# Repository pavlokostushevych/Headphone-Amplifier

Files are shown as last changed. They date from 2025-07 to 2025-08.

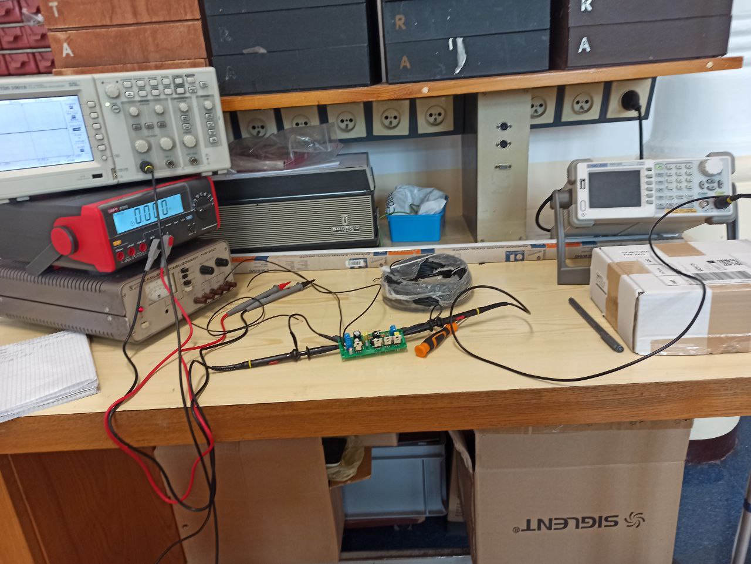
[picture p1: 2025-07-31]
photos/Testing Device.jpg

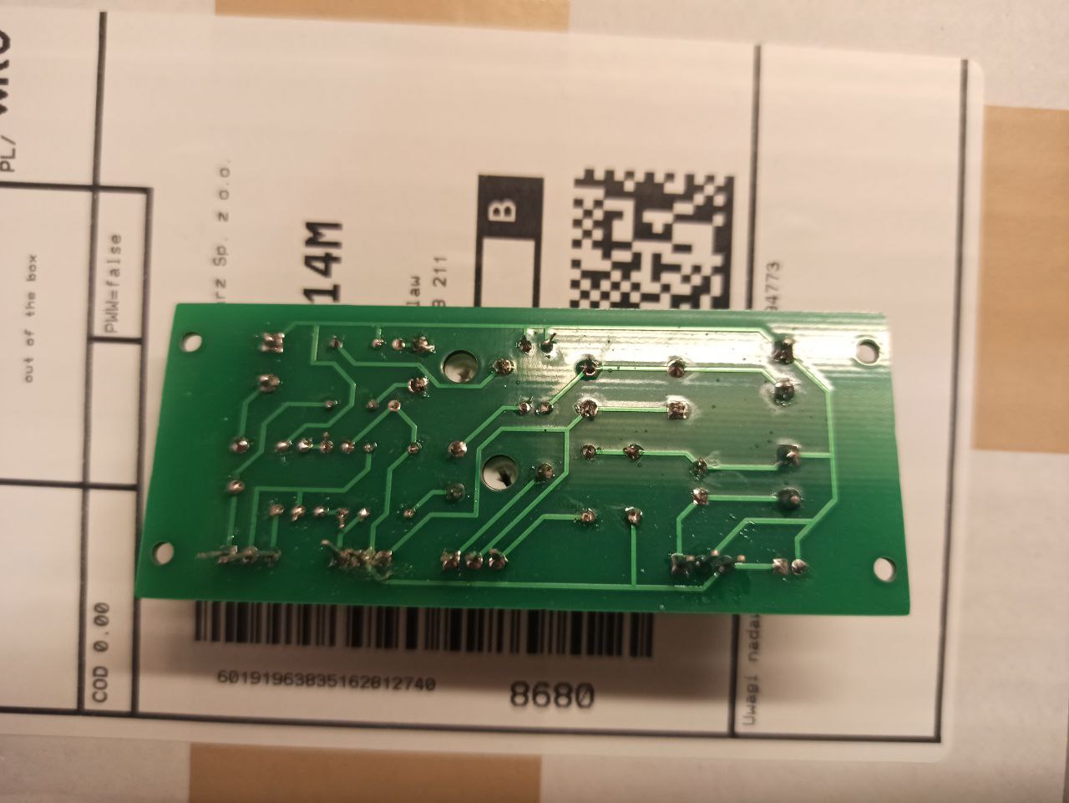
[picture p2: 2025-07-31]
photos/Actual Photo of the PCB from the Soldering Side.jpg

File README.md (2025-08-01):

📄 Wersja polska poniżej – [Przejdź do wersji PL](#pl)

# 🎧 Headphone Amplifier

Class A headphone amplifier project — designed, simulated, and tested.

---

## 📂 Project Structure

- [`docs/`](./docs) — presentations of analysis and simulation in LTspice  
  - Polish version: *[Symulacja i analiza wzmacniacza słuchawkowego klasy A w LTspice](./docs/Symulacja%20i%20analiza%20wzmacniacza%20słuchawkowego%20klasy%20A%20w%20LTspice.pdf)*  
  - English version: *[LTspice Simulation and Analysis of Class A Headphone Amplifier](./docs/LTspice%20Simulation%20and%20Analysis%20of%20Class%20A%20Headphone%20Amplifier.pdf)*  

- [`pcb/`](./pcb) — Gerber files and a screenshot from Gerber Viewer for quick [PCB](./pcb/pcb_gerber_preview.png)
 preview  

- [`photos/`](./photos) — images and visualizations of the device  
  - [3D Simulated View of the PCB](./photos/3D%20Simulated%20View%20of%20the%20PCB.jpg)
  - [Actual Photo of the PCB from the Soldering Side](./photos/Actual%20Photo%20of%20the%20PCB%20from%20the%20Soldering%20Side.jpg)
  - [Testing Device](./photos/Testing%20Device.jpg)

---

## 🛠️ Project Description

The headphone amplifier was designed based on analysis and simulation done in LTspice. The full project includes:  
- Component selection and simulation  
- Schematic and PCB design in KiCad  
- PCB manufacturing files (Gerber)  
- Assembly and soldering of components  
- Testing using power supply, oscilloscope, and multimeter  

---

## 📁 How to Use

- To review the analysis and simulations, please check the PDF files in the [`docs/`](./docs) folder.  
- The Gerber files located in the [`pcb/`](./pcb) folder can be viewed using a Gerber viewer software such as KiCad Gerber Viewer.  
- The [`photos/`](./photos) folder contains visualizations and real photos of the device.  

---

## 📬 Contact

If you have any questions, feel free to reach out:  
- Email: pavlo.kostushevych@gmail.com  
- LinkedIn: [linkedin.com/in/pavlo-kostushevych-ab364b376](https://www.linkedin.com/in/pavlo-kostushevych-ab364b376/)

---

*Thank you for your interest in my project!*

---
## PL

# 🎧 Projekt wzmacniacza słuchawkowego

Projekt wzmacniacza słuchawkowego klasy A — zaprojektowany, zwymiarowany i przetestowany.

---

## 📂 Struktura projektu

- [`docs/`](./docs) — prezentacje analizy i symulacji układu w LTspice  
  - Polskojęzyczna: *[Symulacja i analiza wzmacniacza słuchawkowego klasy A w LTspice](./docs/Symulacja%20i%20analiza%20wzmacniacza%20słuchawkowego%20klasy%20A%20w%20LTspice.pdf)*   
  - Angielska: *[LTspice Simulation and Analysis of Class A Headphone Amplifier](./docs/LTspice%20Simulation%20and%20Analysis%20of%20Class%20A%20Headphone%20Amplifier.pdf)*   

- [`pcb/`](./pcb) — pliki Gerber oraz zrzut ekranu z Gerber Viewer do szybkiego podglądu projektu [PCB](./pcb/pcb_gerber_preview.png)  

- [`photos/`](./photos) — zdjęcia i wizualizacje urządzenia  
  - [3D Simulated View of the PCB](./photos/3D%20Simulated%20View%20of%20the%20PCB.jpg)
  - [Actual Photo of the PCB from the Soldering Side](./photos/Actual%20Photo%20of%20the%20PCB%20from%20the%20Soldering%20Side.jpg)
  - [Testing Device](./photos/Testing%20Device.jpg)

---

## 🛠️ Opis projektu

Wzmacniacz słuchawkowy został zaprojektowany na podstawie analizy i symulacji w LTspice. Całość projektu obejmuje:  
- Dobór i symulację komponentów  
- Projektowanie schematu i PCB w KiCad  
- Wykonanie płytek PCB (plik Gerber)  
- Montaż i lutowanie elementów  
- Testowanie działania za pomocą zasilacza, oscyloskopu i multimetru  

---

## 📁 Jak używać

- Aby przejrzeć analizę i symulacje, zapoznaj się z plikami PDF w folderze [`docs/`](./docs).  
- Pliki Gerber dostępne w folderze [`pcb/`](./pcb) można otworzyć w programie do podglądu Gerber, np. KiCad Gerber Viewer.  
- W folderze [`photos/`](./photos) znajdziesz wizualizacje i zdjęcia rzeczywistego urządzenia.  

---

## 📬 Kontakt

W razie pytań zapraszam do kontaktu:  
- Email: pavlo.kostushevych@gmail.com  
- LinkedIn: [linkedin.com/in/pavlo-kostushevych-ab364b376](https://www.linkedin.com/in/pavlo-kostushevych-ab364b376/)

---

*Dziękuję za zainteresowanie moim projektem!*

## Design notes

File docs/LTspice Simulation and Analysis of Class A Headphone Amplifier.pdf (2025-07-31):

## ELECTRONIC CIRCUIT DESIGN PROJECT

PROJECT TOPIC: CLASS A HEADPHONE AMPLIFIER PAVLO KOSTUSHEVYCH

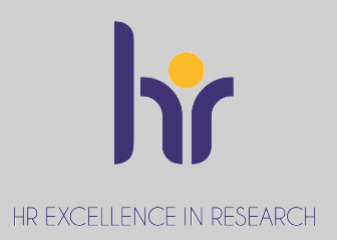
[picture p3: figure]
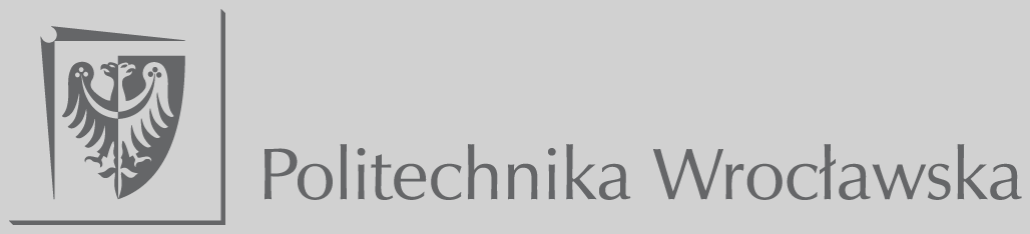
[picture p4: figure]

# Project Schematic

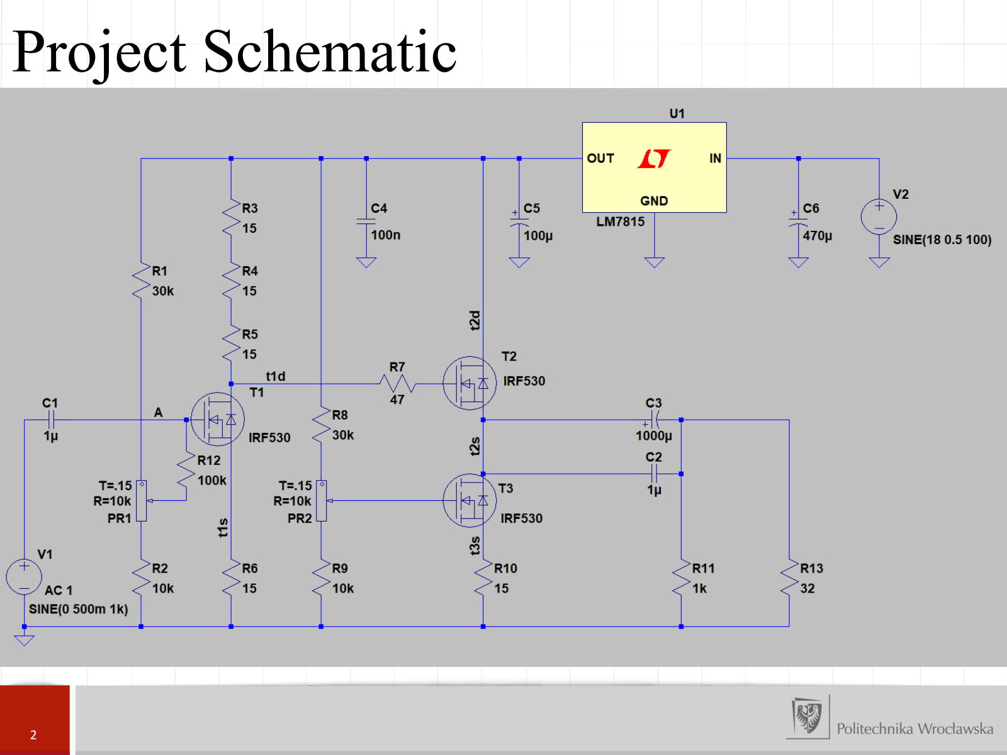
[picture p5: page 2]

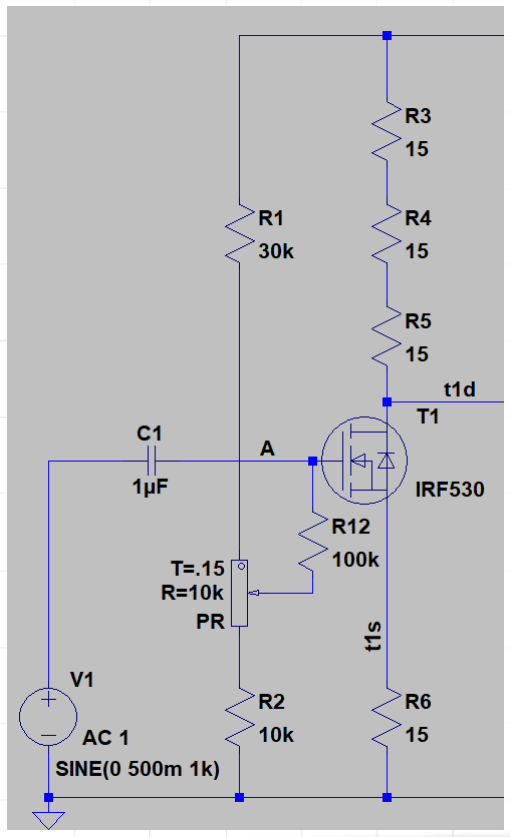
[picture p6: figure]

- The signal is passed through capacitor C1 to the gate of the MOSFET transistor T1.This transistor amplifies the signal by a factor of three, which means the gain is proportional to the ratio of resistors R3, R4, and R5 to resistor R6.This level of amplification is sufficient to connect the amplifier directly to the line output of devices such as CD players, MiniDisc players, or cassette decks.Three identical resistors R3–R5 were used instead of a single 47Ω resistor solely to reduce power dissipation, which totals 450 mW.

# How Does It Work?

## Green input signal: 0.5 V Blue output signal: (12 − 9) / 2 = 1.5 V

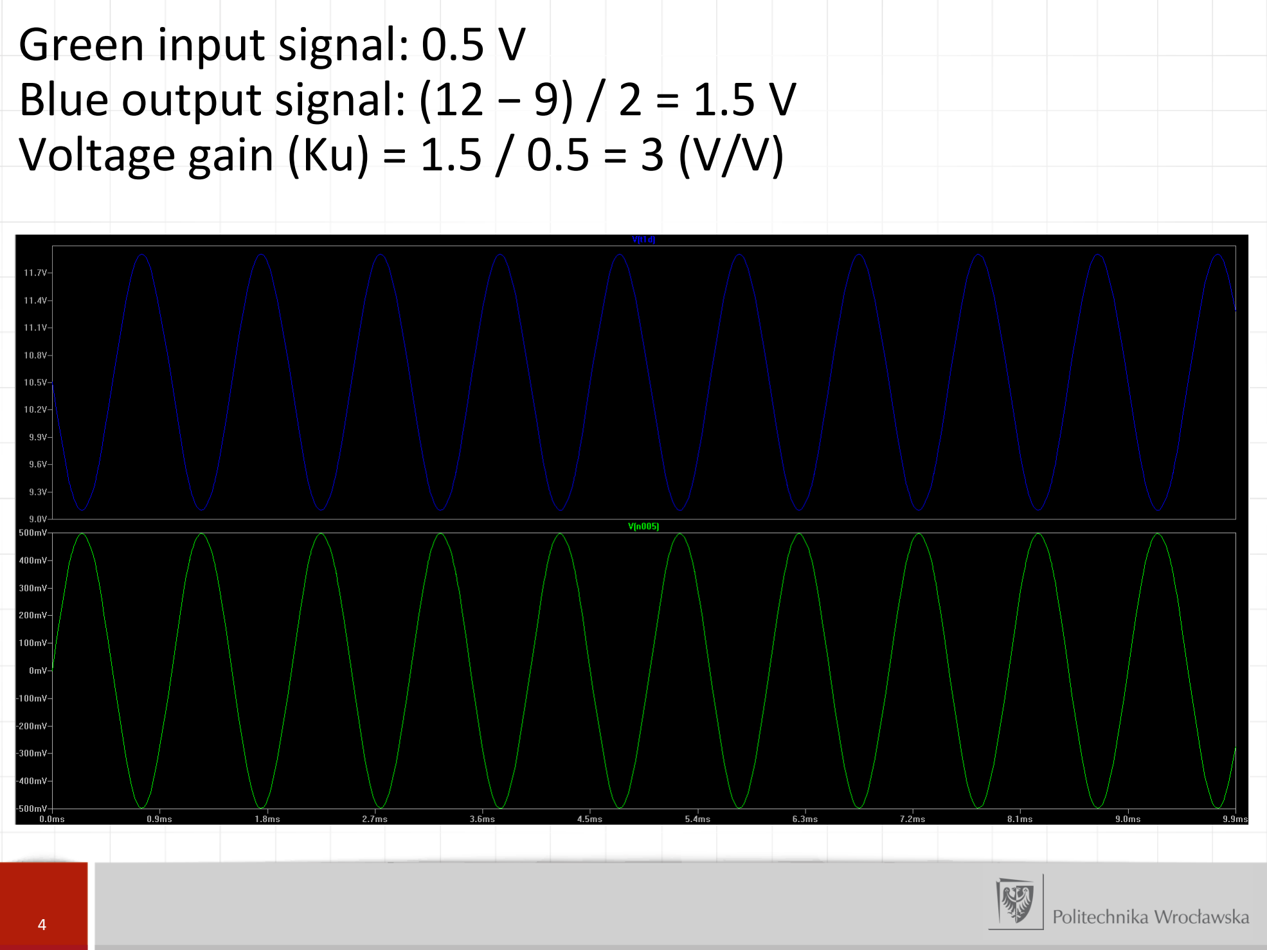
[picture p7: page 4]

## Voltage gain (Ku) = 1.5 / 0.5 = 3 (V/V)

## - The signal, amplified threefold

from the drain of transistor T1,

## is fed to the gate of transistor T2, which operates as a buffer (source follower). To prevent potential oscillations at high frequencies, a low-value resistor R7 is added. To reduce distortion, the buffer T2 is not

loaded with a resistor; instead,

## a current source implemented

using transistor T3 is used.

# How Does It Work?

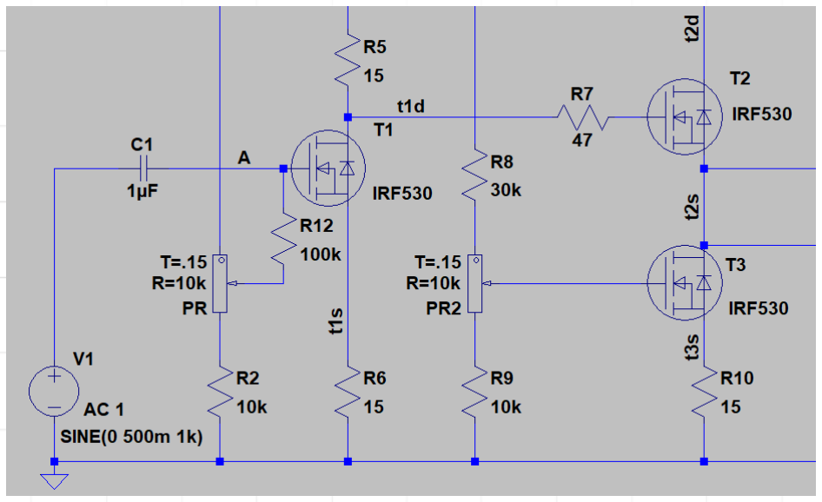
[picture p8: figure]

- To prevent interference from the power supply circuits, a well-regulated supply voltage is required. A supply voltage of 15 V is sufficient to achieve an output power greater than 100 mW into typical
headphones with an impedance
of 32 Ω. However, due to the voltage drop across the regulator, the voltage on capacitor C6 should never be lower than 18 V to ensure stable and interference-free operation of the amplifier.

# How Does It Work?

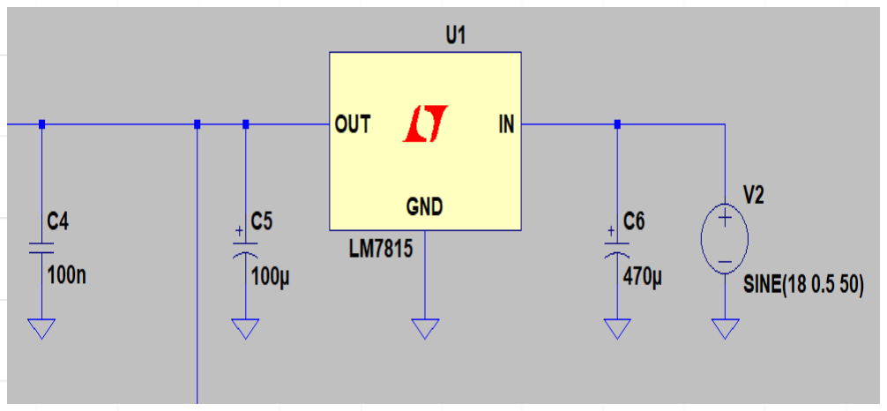
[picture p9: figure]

## Power supply parameters (green signal): 18 V with 0.5 V ripple at 100

Hz

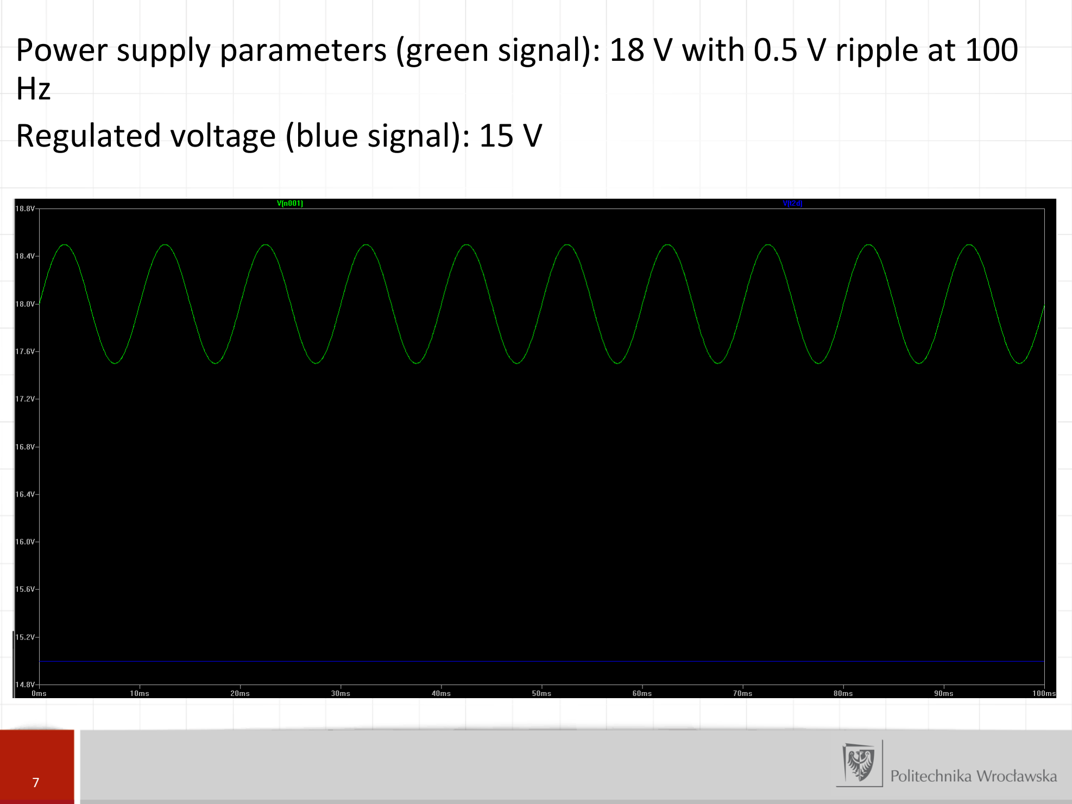
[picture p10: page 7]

## Regulated voltage (blue signal): 15 V

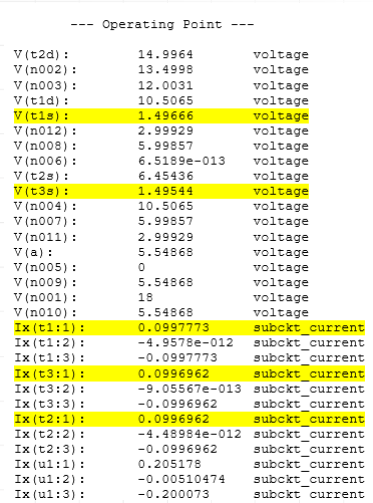
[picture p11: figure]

- To achieve an output power of 100 mW, the quiescent current of the output stage — that is, the quiescent current of transistors T1, T2, and T3 — should be 100 mA or higher. The quiescent currents of T1 and T2+T3 are determined by the values of resistors R6, R10, as well as the voltages at the gates of T1 and T3.The trimmer potentiometers PR1 and PR2 are adjusted so that the quiescent current causes a voltage drop of 1.5 V across resistors R6 (T1s) and R10 (T3s). If these resistors have a value of 15 Ω, this occurs at a quiescent current of 100 mA. Therefore, the entire amplifier — or rather one channel of a stereo amplifier — will draw approximately 200 mA.

# How Does It Work?

## Amplitude characteristic of output voltage (blue) to input voltage (green)

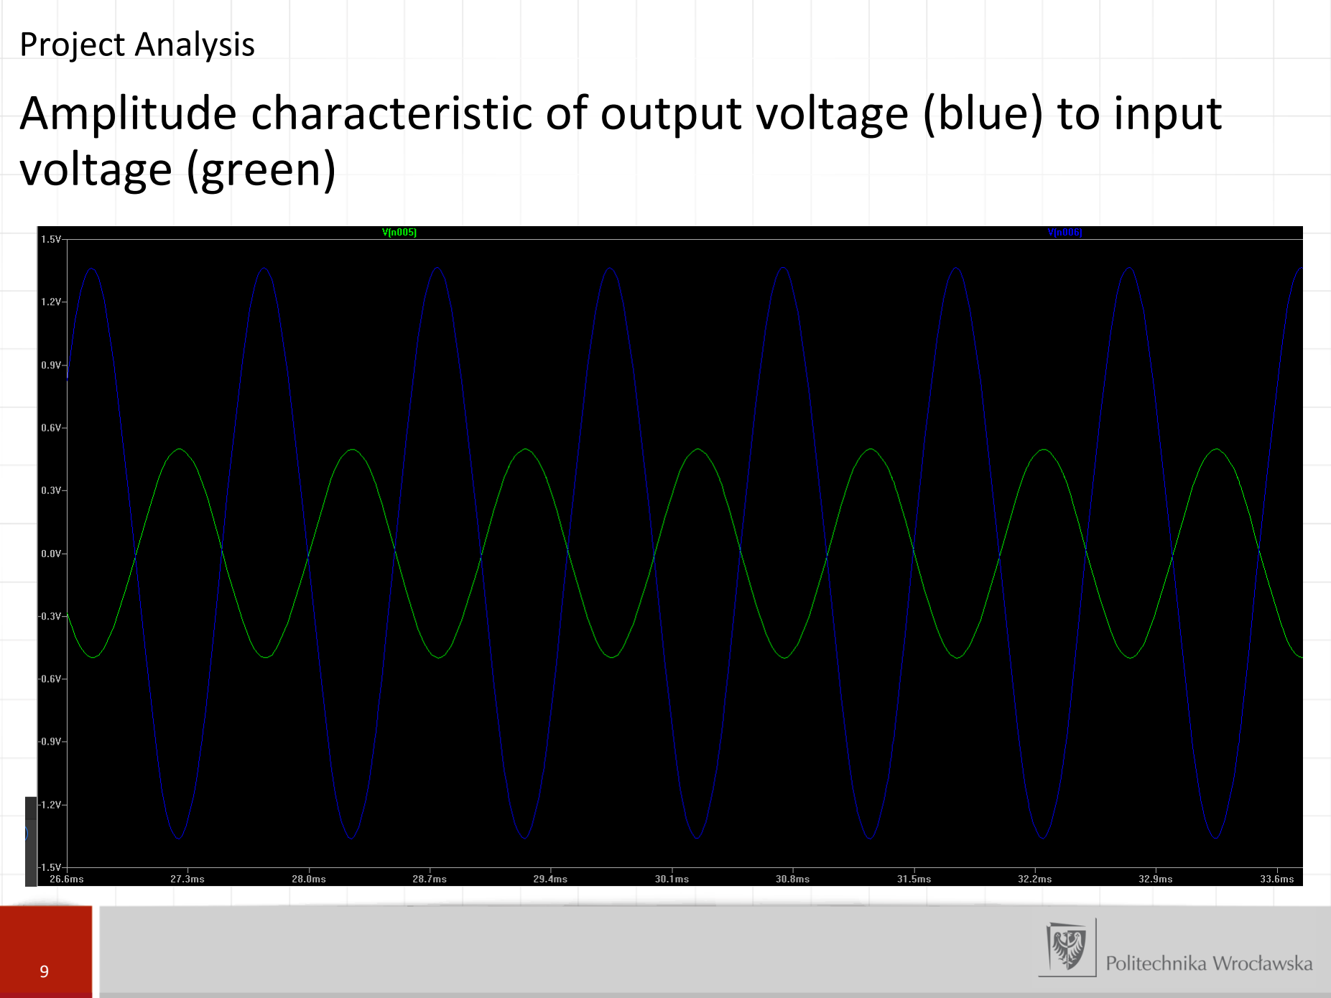
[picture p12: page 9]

Project Analysis

The trimmer potentiometers PR1 and PR2 are adjusted so that the quiescent current equals 100 mA, with no distortion. Characteristics:
R10; 2. R6; 3. Input voltage (green), Output voltage (blue).

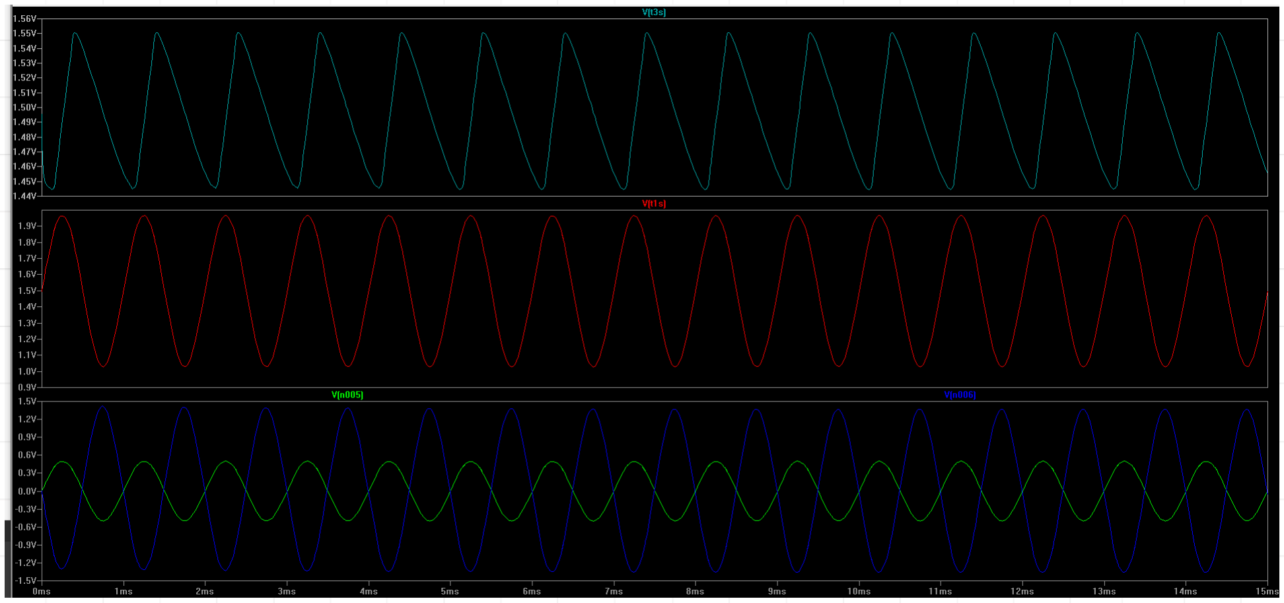
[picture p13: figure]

Potentiometer PR1 is set so that the quiescent current of T1 is 16 mA, and PR2 is set so that the quiescent current of T2 and T3 is 100 mA, in order to observe the resulting distortion.
Characteristics:R10; 2. R6; 3. Input voltage (green), Output voltage (blue).
Due to the low quiescent current in T1, cutoff of the lower amplitude occurs across R6, which causes distortion in T2, T3, and at the output. This can be seen in graphs 1 and 3.

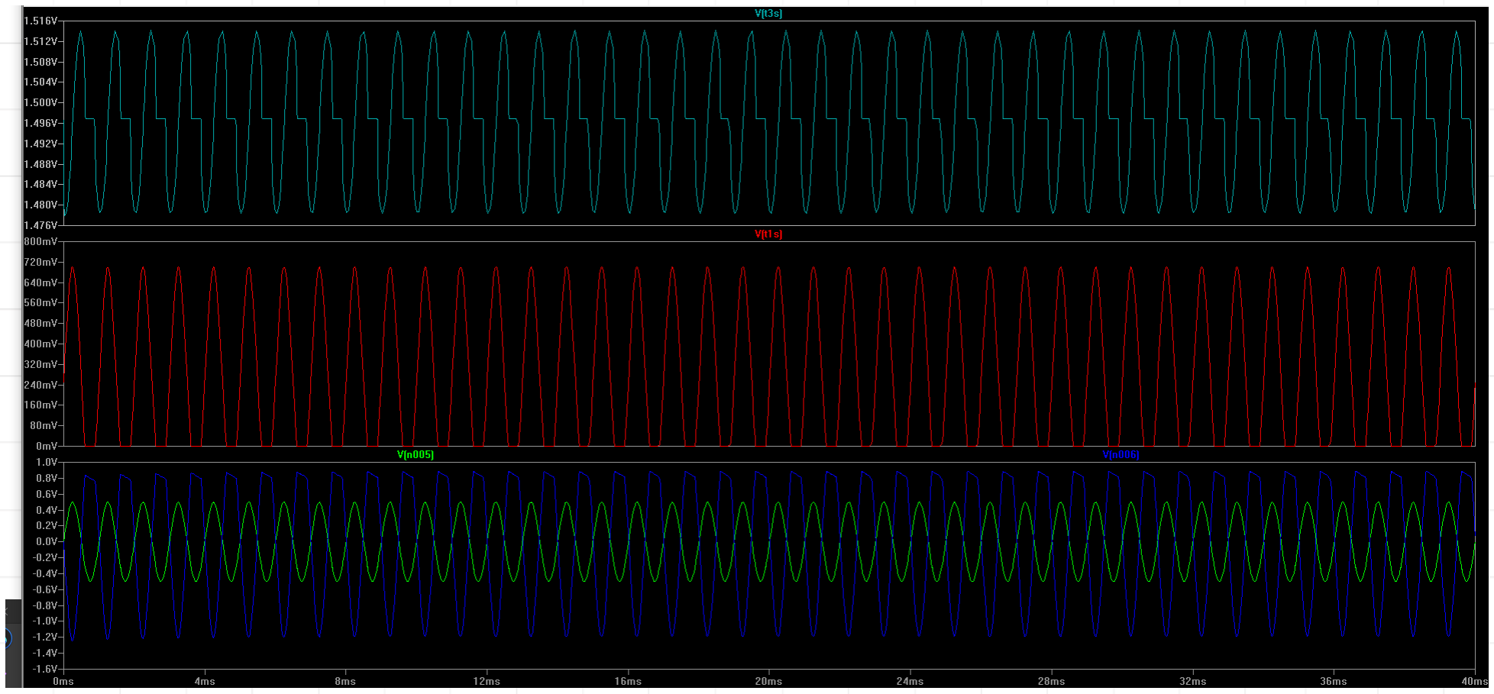
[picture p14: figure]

Potentiometer PR1 is set so that the quiescent current of T1 is 100 mA, and PR2 is set so that the quiescent current of T2 and T3 is 16 mA, in order to observe the resulting distortion.
Characteristics:R10; 2. R6; 3. Input voltage (green), Output voltage (blue).
Due to the low quiescent current in T2 and T3, distortion appears at the output, which can be seen in graphs 1 and 3.

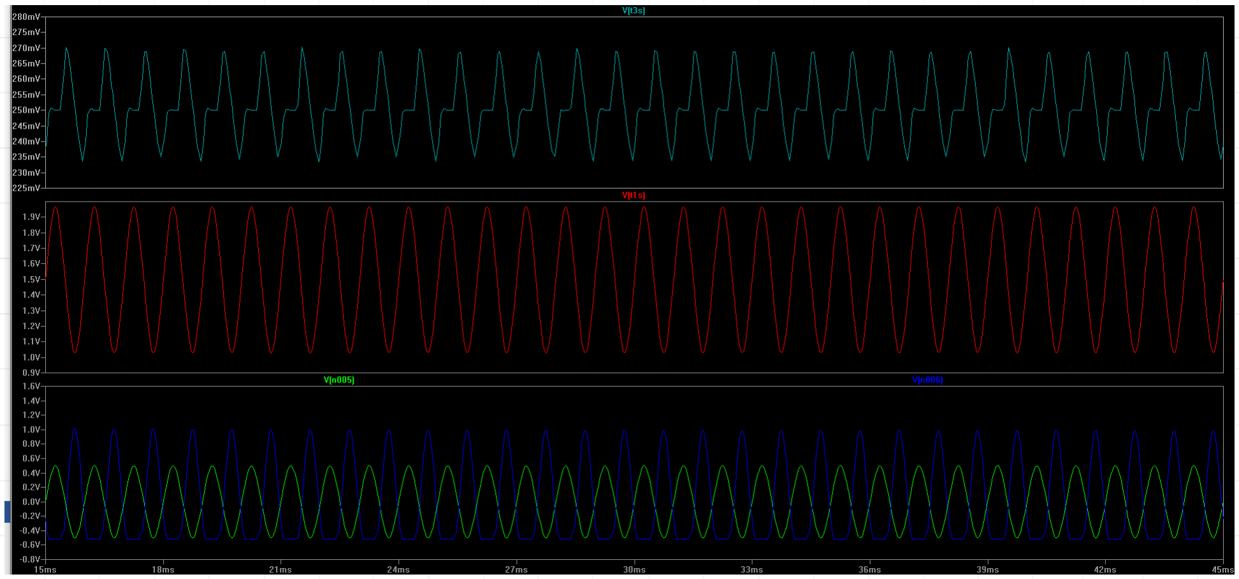
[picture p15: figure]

Amplitude-frequency characteristic of the amplifier (10 Hz – 1 MHz)
To reduce the frequency range, a low-pass filter can be applied at the input to cut off frequencies above 20 kHz.

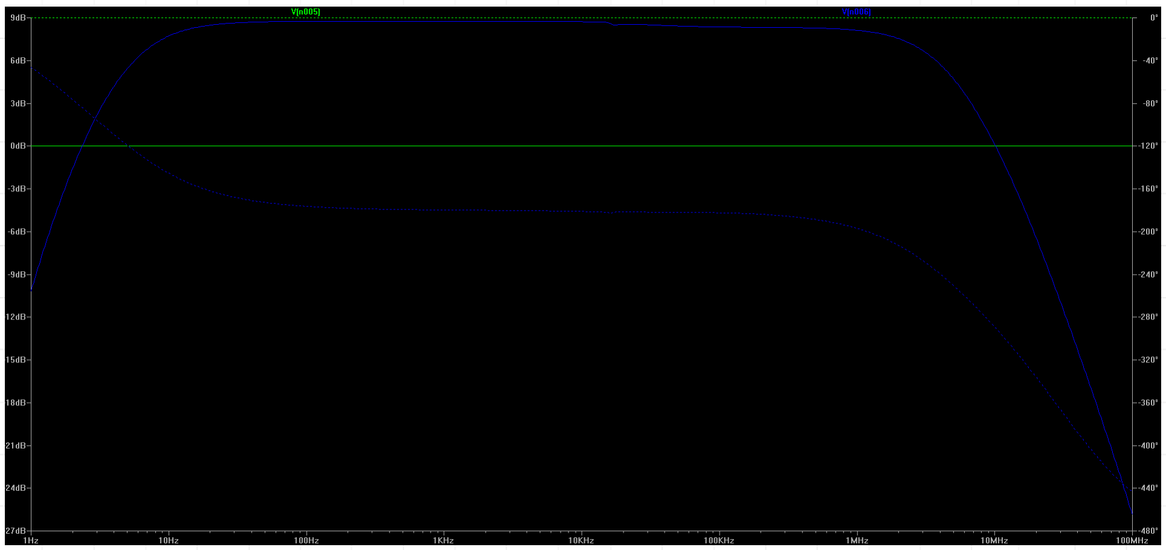
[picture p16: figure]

Effect of temperature on amplifier gain characteristics (f = 10 Hz – 1 MHz) (t = 20°C, 80°C, 120°C).
As shown in the graph, temperature affects the amplitude-frequency characteristics only above 100 kHz, which is beyond the operating range of this amplifier (f = 16 Hz – 20 kHz) and can therefore be neglected.

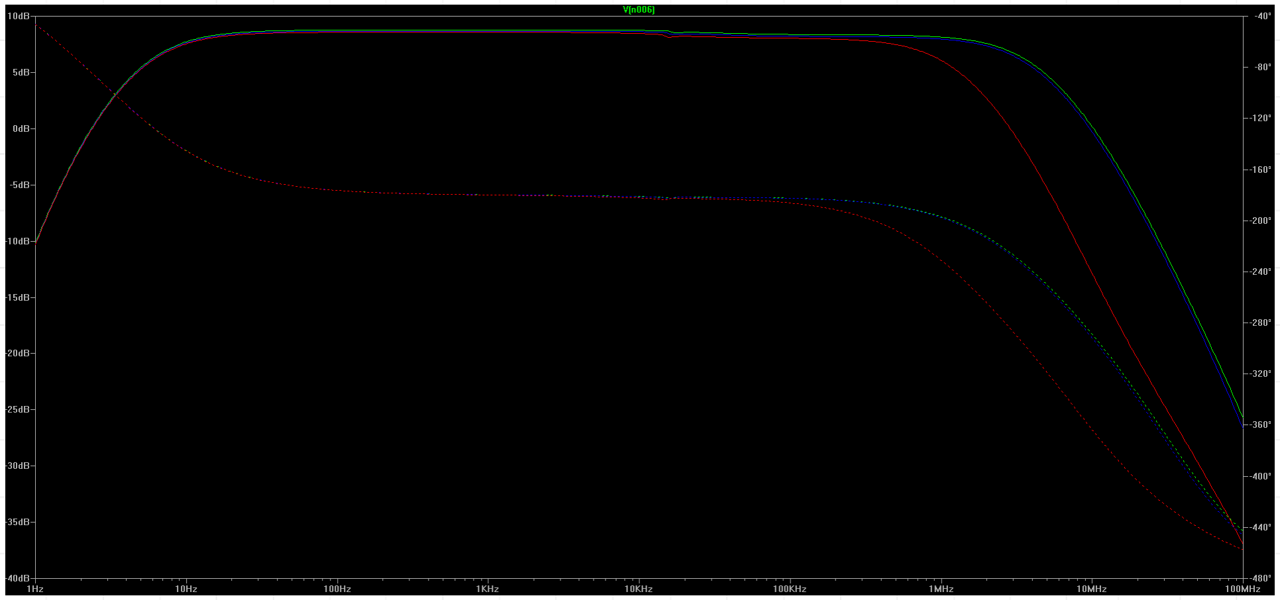
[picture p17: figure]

Effect of temperature on operating points I(R6) – T1; I(R10) – T2, T3 (t = 20°C, 80°C, 120°C).
As shown in the graphs, temperature affects the operating points by reducing the quiescent currents by up to 4 mA, which can be neglected.

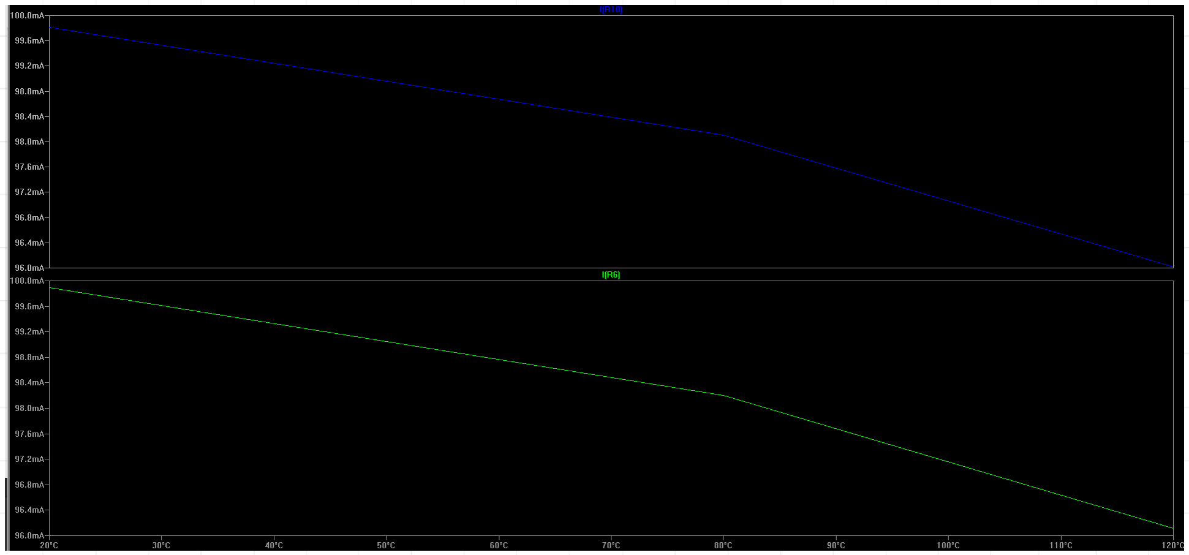
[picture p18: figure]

## Thank you for your attention

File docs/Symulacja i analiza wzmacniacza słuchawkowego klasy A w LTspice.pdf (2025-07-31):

### PROJEKT UKŁADÓW ELEKTRONICZNYCH

TEMAT PROJEKTU: WZMACNIACZ SŁUCHAWKOWY KLASY A PAVLO KOSTUSHEVYCH


# Schemat projektu

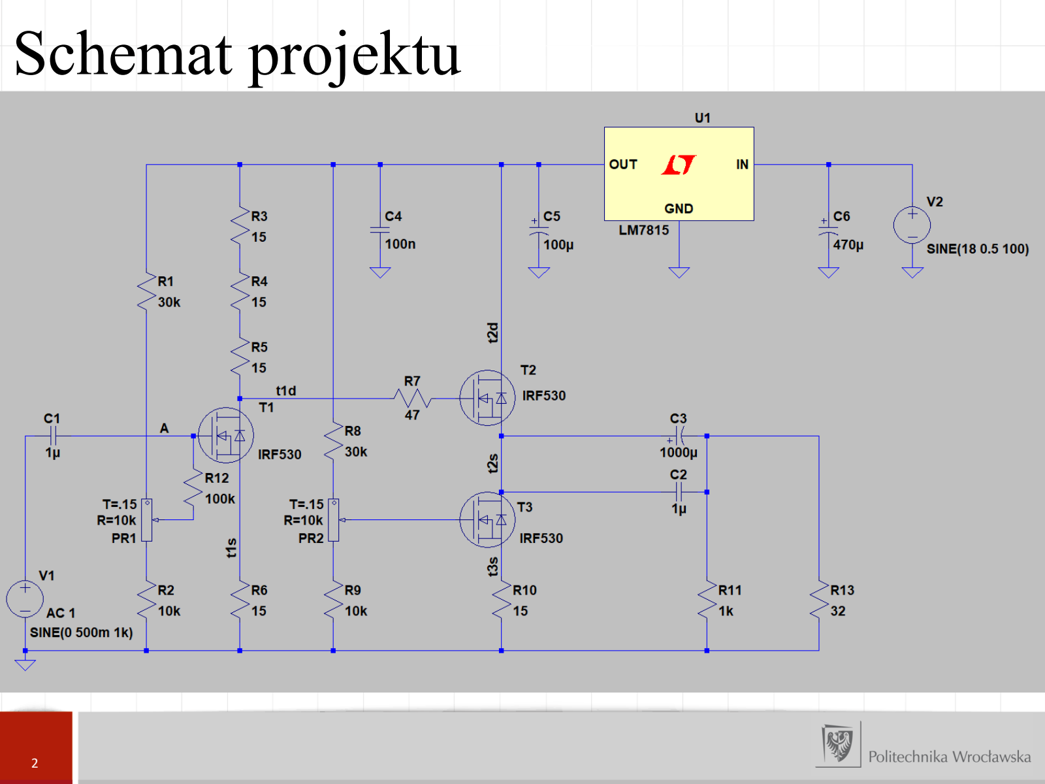
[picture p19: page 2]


- Sygnał jest przesyłany poprzez kondensator C1 do bramki tranzystora MOSFET T1. Ten tranzystor wzmacnia sygnał trzykrotnie, co oznacza, że wzrost sygnału jest proporcjonalny do stosunku rezystorów R3, R4 i R5 do rezystora R6. Taki poziom wzmocnienia jest wystarczający do bezpośredniego podłączenia wzmacniacza do liniowego wyjścia urządzeń takich jak odtwarzacze kompaktowe, minidyski czy magnetofony. W układzie użyto trzech identycznych rezystorów R3..R5 zamiast jednego o wartości 47Ω tylko ze względu na ograniczenie mocy strat, które wynoszą w sumie 450mW.

# Jak to działa?

## Zielony wejściowy sygnał 0.5 (V) Niebieski wyjściowy sygnał (12-9)/2=1.5 (V)

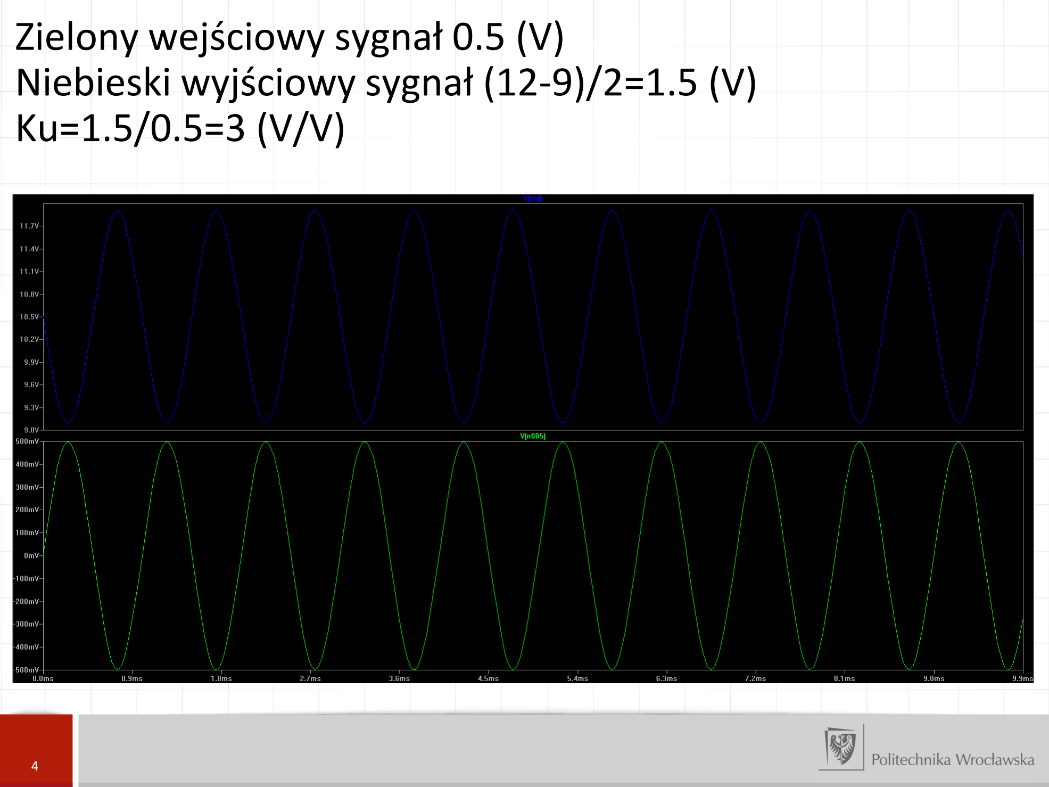
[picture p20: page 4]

## Ku=1.5/0.5=3 (V/V)

### - Sygnał wzmacniany trzykrotnie z drenu tranzystora T1 jest podawany na bramkę tranzystora T2, który działa jako wtórnik. Aby zapobiec ewentualnemu samowzbudzeniu przy wysokich częstotliwościach, dodano rezystor R7 o niskiej wartości. W

celu zmniejszenia zniekształceń,

### wtórnik T2 nie jest obciążany rezystorem, ale zamiast tego używa się źródła prądowego zrealizowanego za pomocą

tranzystora T3.

# Jak to działa?


- Aby zapobiec przenikaniu zakłóceń z obwodów zasilających, konieczne jest dobrze stabilizowane napięcie zasilania. Napięcie zasilające o wartości 15V jest wystarczające do uzyskania mocy wyjściowej większej niż 100mW na typowej rezystancji słuchawek wynoszącej 32Ω. Jednak ze względu na spadek napięcia na stabilizatorze, napięcie na kondensatorze C6 nigdy nie powinno być niższe niż 18V, aby zapewnić stabilne i niezakłócone działanie wzmacniacza.

# Jak to działa?


## Parametry zasilania(zielony sygnał): 18 (V) z pulsacjami 0.5 (V) 100 (Hz) Stabilizowane napięcie(niebieski sygnał): 15 (V)

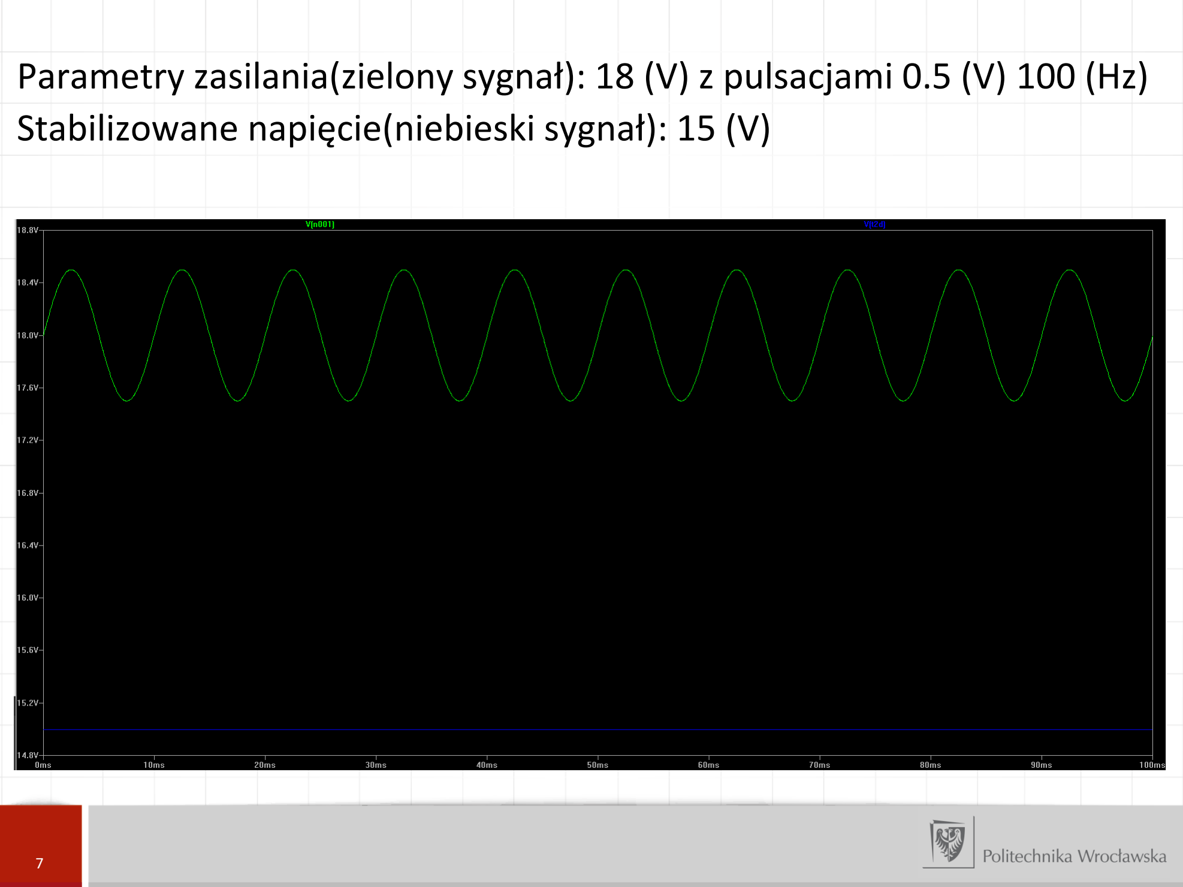
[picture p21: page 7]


- Aby uzyskać moc 100mW, prąd stopnia końcowego, czyli prąd spoczynkowy tranzystorów T1 , T2, T3 powinien wynosić 100mA lub więcej. O prądach spoczynkowych T1 oraz T2+T3 decydują zarówno wartości rezystorów R6, R10, jak i napięcia na bramkach T1, T3. Potencjometry montażowe PR1, PR2 tak ustawione, by prąd spoczynkowy wywoływał na rezystorach R6(t1s) i R10(t3s) spadek napięcia równy 1,5V. Jeśli rezystory te będą mieć wartość 15Ω, nastąpi to przy prądzie spoczynkowym 100mA. Cały wzmacniacz, a właściwie jeden kanał wzmacniacza stereo będzie więc pobierał prąd około 200mA.

# Jak to działa?

## Charakterystyka amplitudowa wyjściowego napięcia(niebieski) do wejściowego napięcia(zielony)

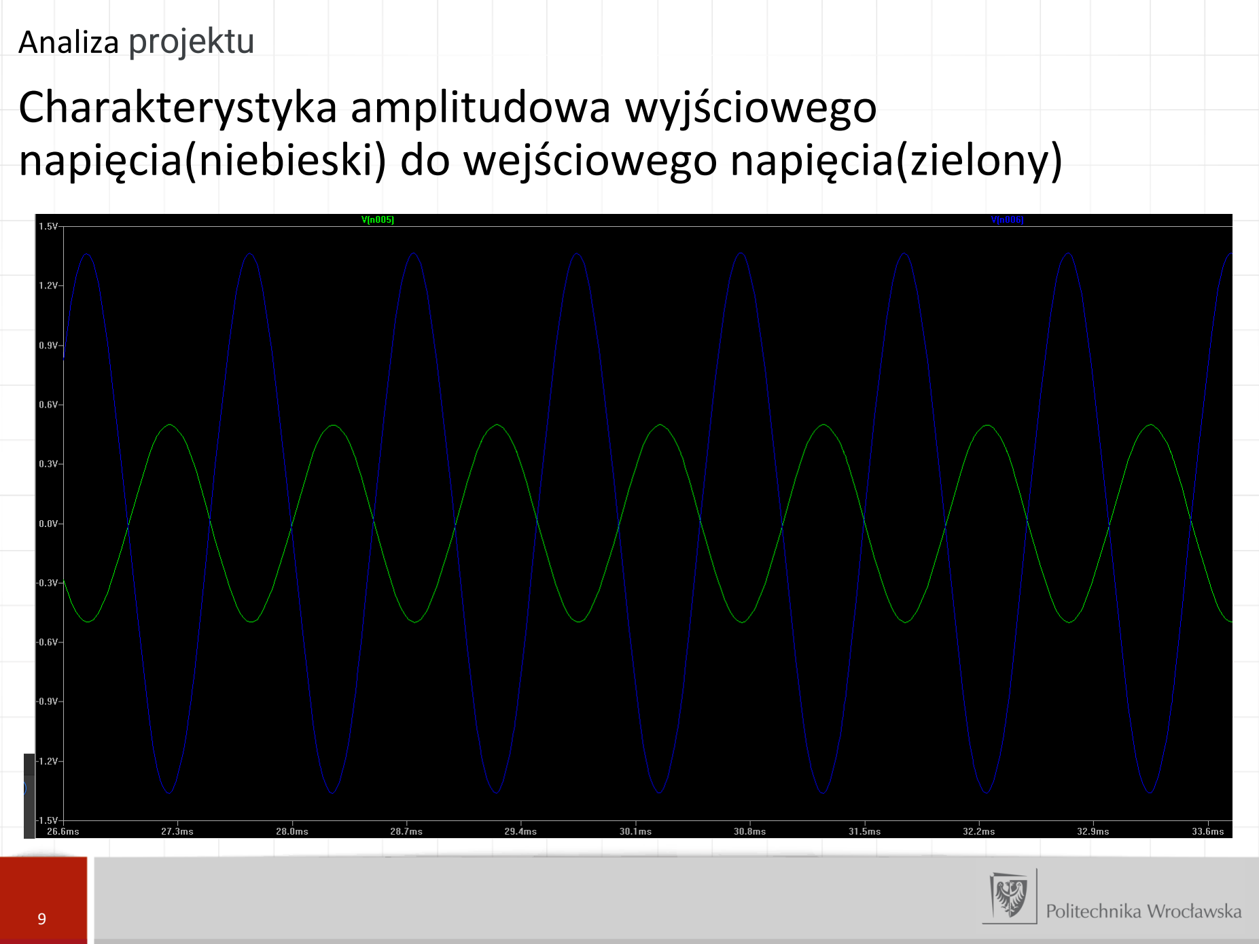
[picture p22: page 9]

Analiza projektu

Potencjometry PR1, PR2 ustawione tak, by prąd spoczynkowy = 100mA, bez zniekształceń. Charakterystyki:
1. R10; 2. R6; 3. Uwe (zielony), Uwy (niebieski).


Potencjometr PR1 ustawiony tak, by prąd spoczynkowy T1= 16mA, PR2 ustawiony tak, by prąd spoczynkowy T2,T3 = 100mA, żeby zobaczyć jakie możemy otrzymać zniekształcenia. Charakterystyki:
1. R10; 2. R6; 3. Uwe (zielony), Uwy (niebieski).
Ze względu na niski prąd spoczynkowy na T1, na R6 otrzymujemy odcięcie dolnej amplitudy, z tego powodu otrzymujemy zniekształcenia na T2,T3 i wyjściu. Co można zobaczyć na wykresach 1 i 3.


Potencjometr PR1 ustawiony tak, by prąd spoczynkowy T1= 100mA, PR2 ustawiony tak, by prąd spoczynkowy T2,T3 = 16mA, żeby zobaczyć jakie możemy otrzymać zniekształcenia. Charakterystyki:
1. R10; 2. R6; 3. Uwe (zielony), Uwy (niebieski).
Ze względu na niski prąd spoczynkowy na T2,T3 otrzymujemy zniekształcenia na wyjściu. Co można zobaczyć na wykresach 1 i 3.


Charakterystyka amplitudowo częstotliwościowa wzmacniacza (10hz – 1Mhz)
Dla zmniejszenia częstotliwościowego zakresu można zastosować filtr dolnoprzepustowy na wejściu do odcięcia częstotliwości wyższych niż 20 khz


Charakterystyka wpływu temperatury na wzmocnienie wzmacniacza (f=10hz – 1Mhz) (t=20 ◦C, 80 ◦C, 120 ◦C).

Jak można zobaczyć na wykresie temperatura wpływa na charakterystyki amplitudowo-częstotliwościowe dopiero po 100 khz, co jest poza zakresem pracy tego wzmacniacza (f=16hz-20khz), co można pominąć.


Charakterystyka wpływu temperatury na punkty pracy I(R6) – T1; I(R10) – T2,T3 (t=20 ◦C, 80 ◦C, 120 ◦C).

Jak można zobaczyć na wykresach temperatura wpływa na punkty pracy zmniejszając prądy spoczynkowe na 4 mA, co można pominąć.


## Dziękuję za uwagę

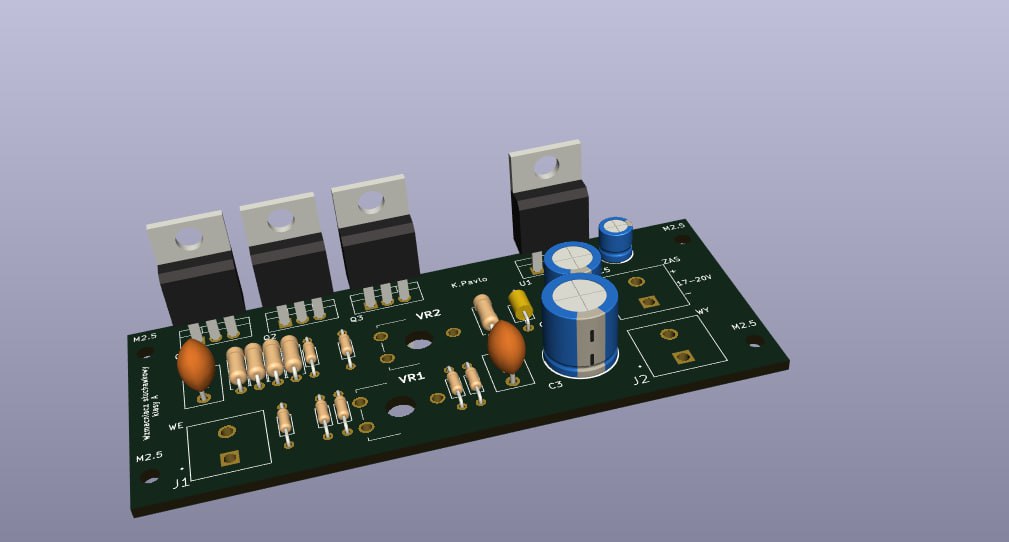
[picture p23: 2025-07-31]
photos/3D Simulated View of the PCB.jpg

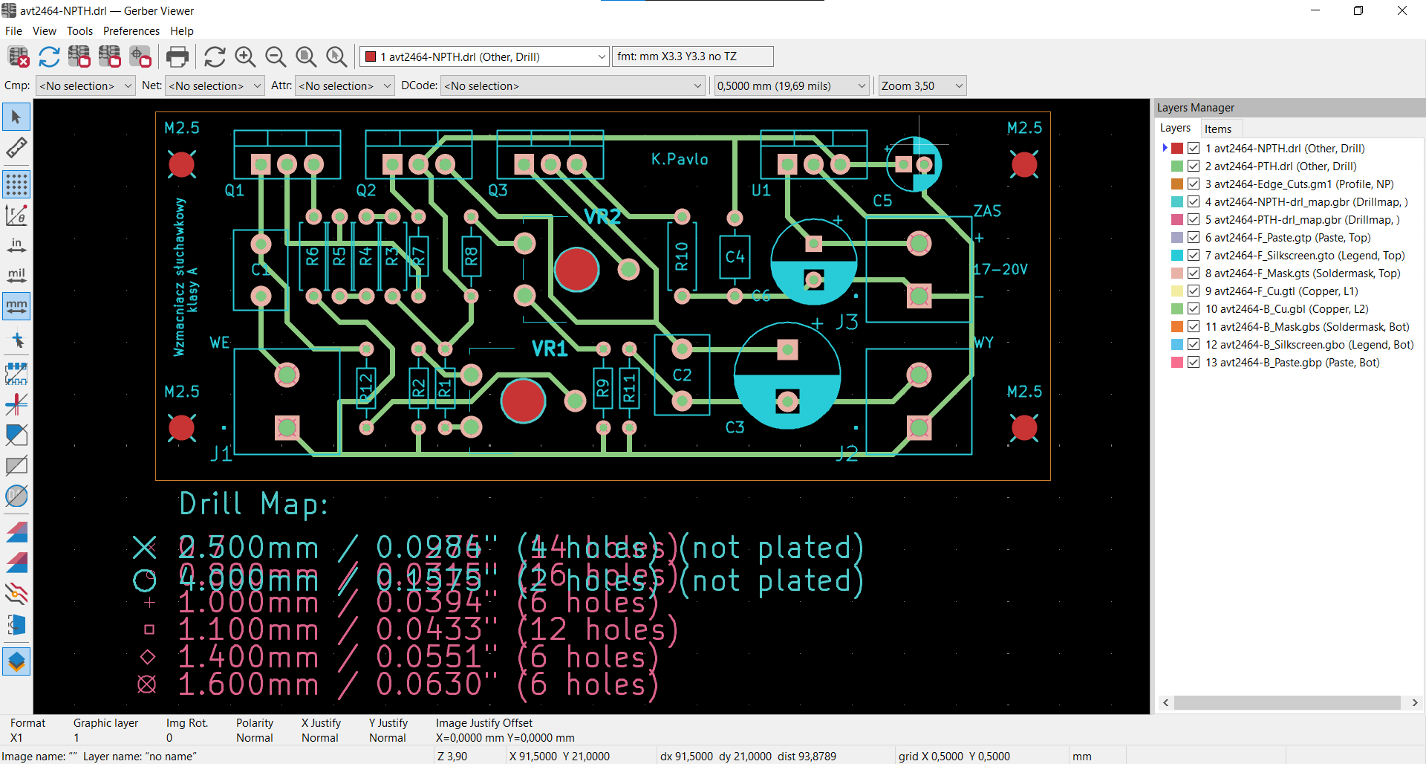
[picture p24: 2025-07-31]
pcb/pcb_gerber_preview.png
